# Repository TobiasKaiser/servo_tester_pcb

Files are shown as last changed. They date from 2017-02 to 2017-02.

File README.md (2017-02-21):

servo_tester
============
*An electronics project for me to learn how to design PCBs in KiCad and assemble it with SMD components.*

Purpose
-------

* Generate a PWM signal of approximately 20 ms period with variable duty cycle.
* The duty cycle can be controlled by a potentiometer.
* For user feedback, the currently set value should be displayed on a 4 digit seven-segment display.
* Through an additional push button, the user should be able to cycle through a number of settings to control parameters of the PWM output.
* This PWM output can be used to control the position of a servo motor.
* To have more, interesting stuff on the board, I put a little buck converter (instead of a linear voltage regulator like the 7805) on the board.

Hardware
--------

**Corrected** circuit here:
...

**Note: Some of the hardware problems which are corrected in this circuit file are not yet corrected in the board file.**

Hardware Problems
-----------------

As I expected, not everything worked out with the first PCBs and components that I have ordered. 

* Before the manufactured PCBs arrived, I already noticed that R5, R6, R7, R8 are incorrectly placed at the common electrode of the multiplexed seven-segment LED display.
Using the regular way of multiplexing this display, this would have resulted in different brightnesses depending on the number of lights turned on of each digit.
I could 

* The resistor R1 was incorrectly connecting the feedback output of the step down converter with VCC instead of GND.
I could solve this problem by adding the resistor right between beside two adjacent pins of the switching converter.

* Some of the capacitors that I have ordered were too large and could not fit on the PCB, and the push button switch that I ordered was accidentally a through-hole part. 
Next time I should spend a little more time on selecting the matching components. 

* Ground plane connection issue. 

* ADC problem (see next section)

Reading the potentiometer without built-in ADC module
-----------------------------------------------------

Unfortunately, the ATtiny2313 has no built-in ADC. The conversion has to be done somehow else using a comparator therefore.
The first attempt was to use the technique described in the Atmel application note AVR401 (the charging transient of the capacitor at the analog comparator input A is used to determine the current value of the analog comparator input B, which is the potentiometer).
This turned out to be too inaccurate.

Firmware
--------

The firmware can be found in the separate repository (servo_tester_firmware)[https://github.com/TobiasKaiser/servo_tester_firmware].

License
-------

* TO-263 footprint from https://github.com/cpavlina/kicad-pcblib
* Different license for Poti.pretty (see Poti.pretty/LICENSE.md)

For everything else:

Copyright (c) 2016 Tobias Kaiser <mail@tb-kaiser.de>

Permission is hereby granted, free of charge, to any person obtaining a copy of this hardware, software, and associated documentation files (the "Product"), to deal in the Product without restriction, including without limitation the rights to use, copy, modify, merge, publish, distribute, sublicense, and/or sell copies of the Product, and to permit persons to whom the Product is furnished to do so, subject to the following conditions:

The above copyright notice and this permission notice shall be included in all copies or substantial portions of the Product.

THE PRODUCT IS PROVIDED "AS IS", WITHOUT WARRANTY OF ANY KIND, EXPRESS OR IMPLIED, INCLUDING BUT NOT LIMITED TO THE WARRANTIES OF MERCHANTABILITY, FITNESS FOR A PARTICULAR PURPOSE AND NONINFRINGEMENT. IN NO EVENT SHALL THE AUTHORS OR COPYRIGHT HOLDERS BE LIABLE FOR ANY CLAIM, DAMAGES OR OTHER LIABILITY, WHETHER IN AN ACTION OF CONTRACT, TORT OR OTHERWISE, ARISING FROM, OUT OF OR IN CONNECTION WITH THE PRODUCT OR THE USE OR OTHER DEALINGS IN THE PRODUCT.

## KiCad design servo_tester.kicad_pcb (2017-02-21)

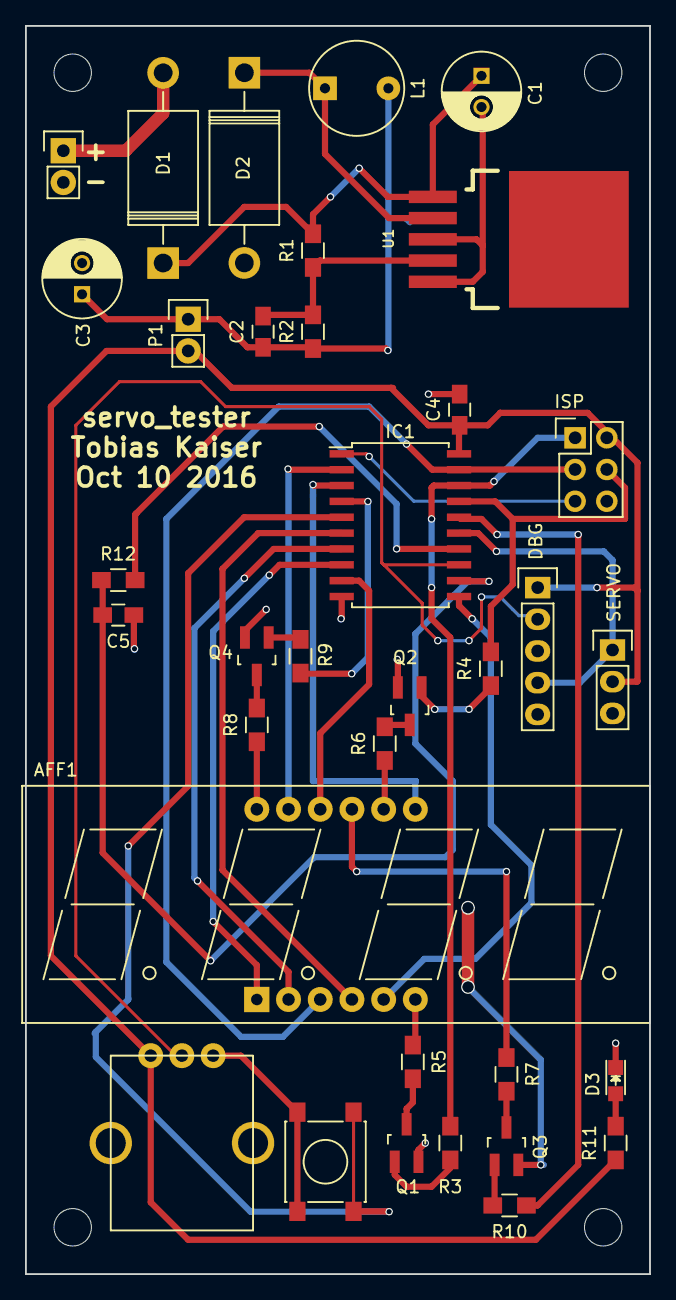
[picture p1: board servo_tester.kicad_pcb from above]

Board: 2 copper layers, 50.0 x 100.0 mm, 35 parts (0 on the bottom side), 38 nets.

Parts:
AFF1: CC56-12; Cx56-12
C1: 470uF/50V; C_Radial_D6.3_L11.2_P2.5
C2: 10nF; C_0805_HandSoldering
C3: 470uF/10V; C_Radial_D6.3_L11.2_P2.5
C4: 100nF; C_0805_HandSoldering
C5: 4.7nF; C_0805_HandSoldering
D1, D2: 1N5825; Diode_DO-201AD_Horizontal_RM15
D3: LED; LED_0805
DBG: CONN_01X05; Pin_Header_Straight_1x05
IC1: ATTINY2313-S; SOIC-20_7.5x12.8mm_Pitch1.27mm
ISP: AVR-ISP-6; Pin_Header_Straight_2x03
L1: 68uH; INDUCTOR_V
P1, P2: CONN_01X02; Pin_Header_Straight_1x02
Q1, Q2, Q3, Q4: BC847; SOT-23_Handsoldering
R1, R3, R4, R9, R10, R11: 1k; R_0805_HandSoldering
R2: 3k; R_0805_HandSoldering
R5, R6, R7, R8: 300; R_0805_HandSoldering
R12: 27k; R_0805_HandSoldering
RV1: POT; POTI_PTV09A
SERVO: CONN_01X03; Pin_Header_Straight_1x03
SW1: SW_PUSH; SW_SPST_PTS645
U1: LM2596; TO-263-5

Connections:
+5V: C4.1, DBG.1, IC1.20, ISP.2, P1.2, R11.1, RV1.3, SERVO.2
+12V: D1.2, P2.1
/RST: IC1.1, ISP.5
/a: AFF1.11, IC1.2
/b: AFF1.7, IC1.3
/c: AFF1.4, IC1.6
/c1: IC1.4, R9.1
/c2: IC1.16, R10.1
/c3: IC1.17, ISP.4, R4.2
/c4: IC1.18, ISP.1, R3.2
/d: AFF1.2, IC1.7
/dp: AFF1.3, IC1.19, ISP.3
/e: AFF1.1, IC1.8
/f: AFF1.10, IC1.9
/g: AFF1.5, IC1.11
/pot_in: DBG.2, IC1.13, RV1.2
/pwm_out: DBG.4, IC1.15, SERVO.1
GND: C1.2, C3.2, C4.2, C5.1, D2.2, D3.1, DBG.5, IC1.10, ISP.6, P2.2, Q1.2, Q2.2, Q3.2, Q4.2, RV1.1, SERVO.3, SW1.2, U1.3, U1.5
unnamed: AFF1.6, R5.1
unnamed: AFF1.8, R6.1
unnamed: AFF1.9, R7.1
unnamed: AFF1.12, R8.1
unnamed: C1.1, D1.1, R1.2, U1.1
unnamed: C2.1, C3.1, L1.2, P1.1, R2.1
unnamed: C2.2, R1.1, R2.2, U1.4
unnamed: C5.2, IC1.12, R12.1
unnamed: D2.1, L1.1, U1.2
unnamed: D3.2, R11.2
unnamed: IC1.5, SW1.1
unnamed: IC1.14, R12.2
unnamed: Q1.1, R3.1
unnamed: Q1.3, R5.2
unnamed: Q2.1, R4.1
unnamed: Q2.3, R6.2
unnamed: Q3.1, R10.2
unnamed: Q3.3, R7.2
unnamed: Q4.1, R9.2
unnamed: Q4.3, R8.2

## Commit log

2016-10-09 added some stuff
    [servo_tester.sch]
2016-10-10 almost done.
    now still need to forward-annotate 1x 100nF decoupeling capacitor and maybe a LED.
    [servo_tester.kicad_pcb, servo_tester.sch]
2016-10-10 save before forward annotate test
    [servo_tester.kicad_pcb, servo_tester.sch]
2016-10-10 starting with drc now
    [servo_tester.kicad_pcb, servo_tester.sch]
2016-10-10 oops... attiny2313 doesnt have adc...
    [servo_tester.kicad_pcb, servo_tester.sch]
2016-10-10 adjusted - adc now via AVR400 application note
    [servo_tester.kicad_pcb, servo_tester.sch]
2016-10-10 final check again...
    [servo_tester.kicad_pcb, servo_tester.sch]
2016-10-10 Submitted to seeedstudio
    [servo_tester.kicad_pcb]
2016-11-06 First firmware attempt: Using AVR 400
    ADC via step charging capacitor and comparing with pot.
    This works well when the servo PWM is unchanged, but does not work well if the servo pwm changes.
2016-11-10 Added missing license file for pot footprint
2016-11-10 fixed 2 problems in schematic (3 -> 8 Rs, reglt.)
    [servo_tester.sch]
2016-11-12 ground connection fix, pcb still neds new netlist
    [servo_tester.kicad_pcb]
